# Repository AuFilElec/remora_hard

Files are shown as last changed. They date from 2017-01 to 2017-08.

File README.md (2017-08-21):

# remora_hard
PCB Remora v1.4 - gestionnaire de chauffage électrique

La **Remora** permet de piloter 7 zones de chauffage électrique via les fils pilotes. Mais aussi de récupérer la téléinformation de votre compteur Enedis et piloter votre ballon d'eau chaude.

**Schematic**

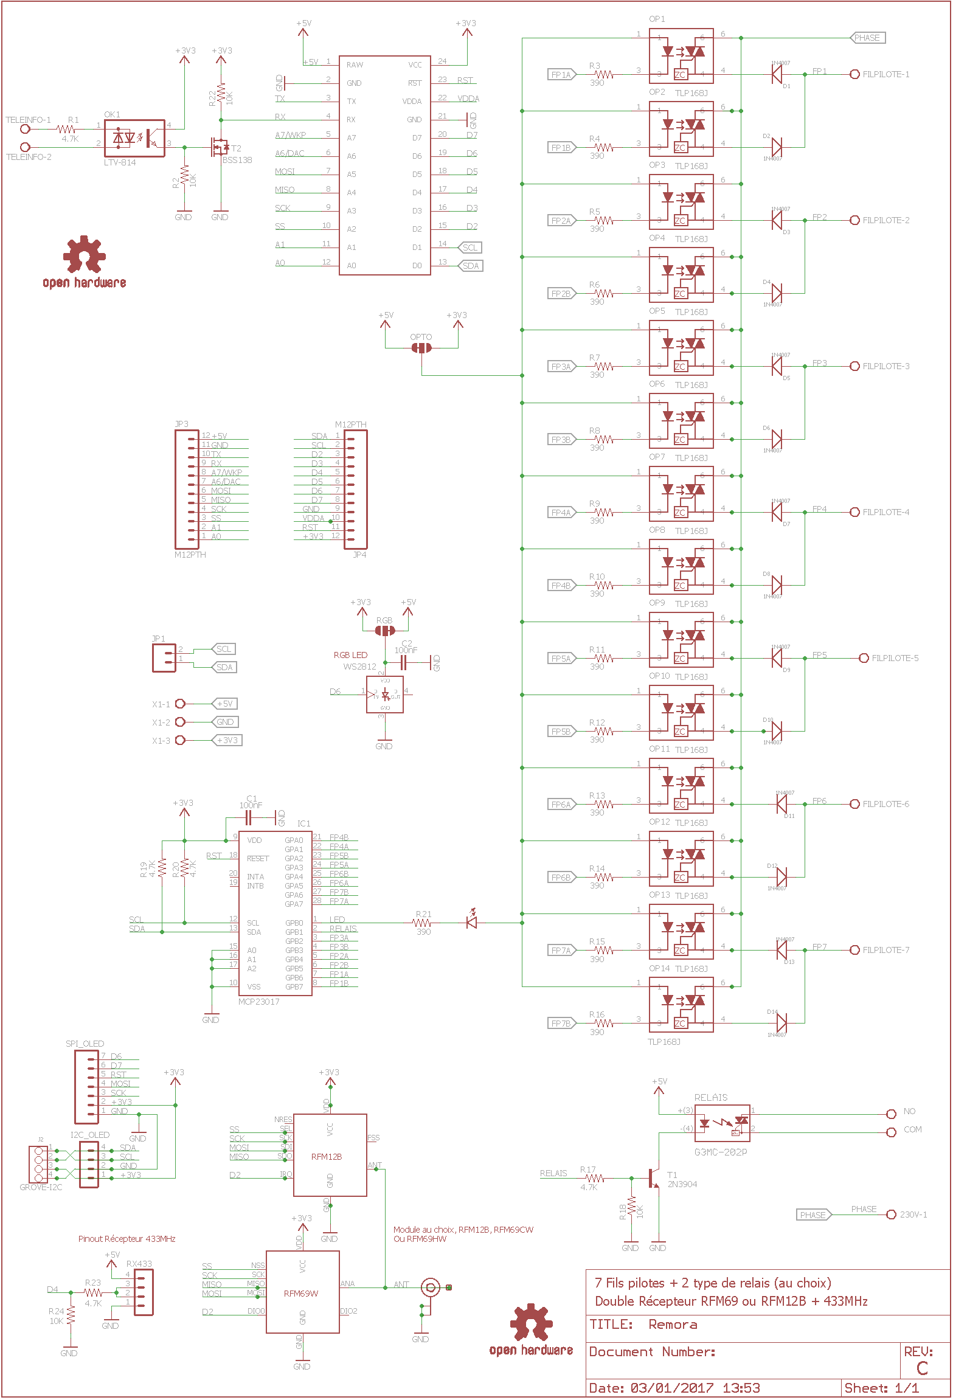
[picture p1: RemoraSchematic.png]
schéma carte Remora


**PCB**

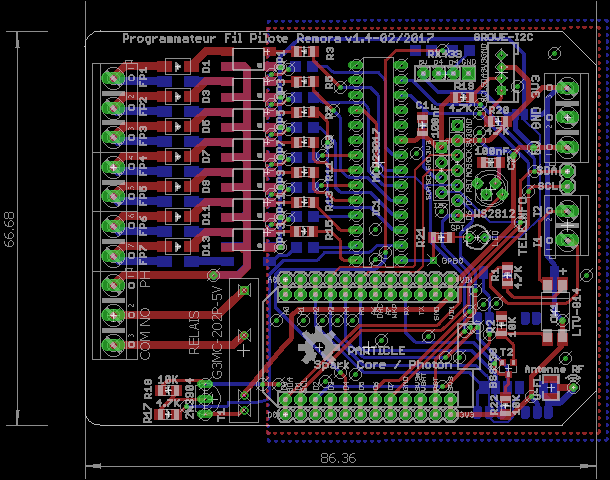
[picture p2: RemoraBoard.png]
PCB Remora v1.4


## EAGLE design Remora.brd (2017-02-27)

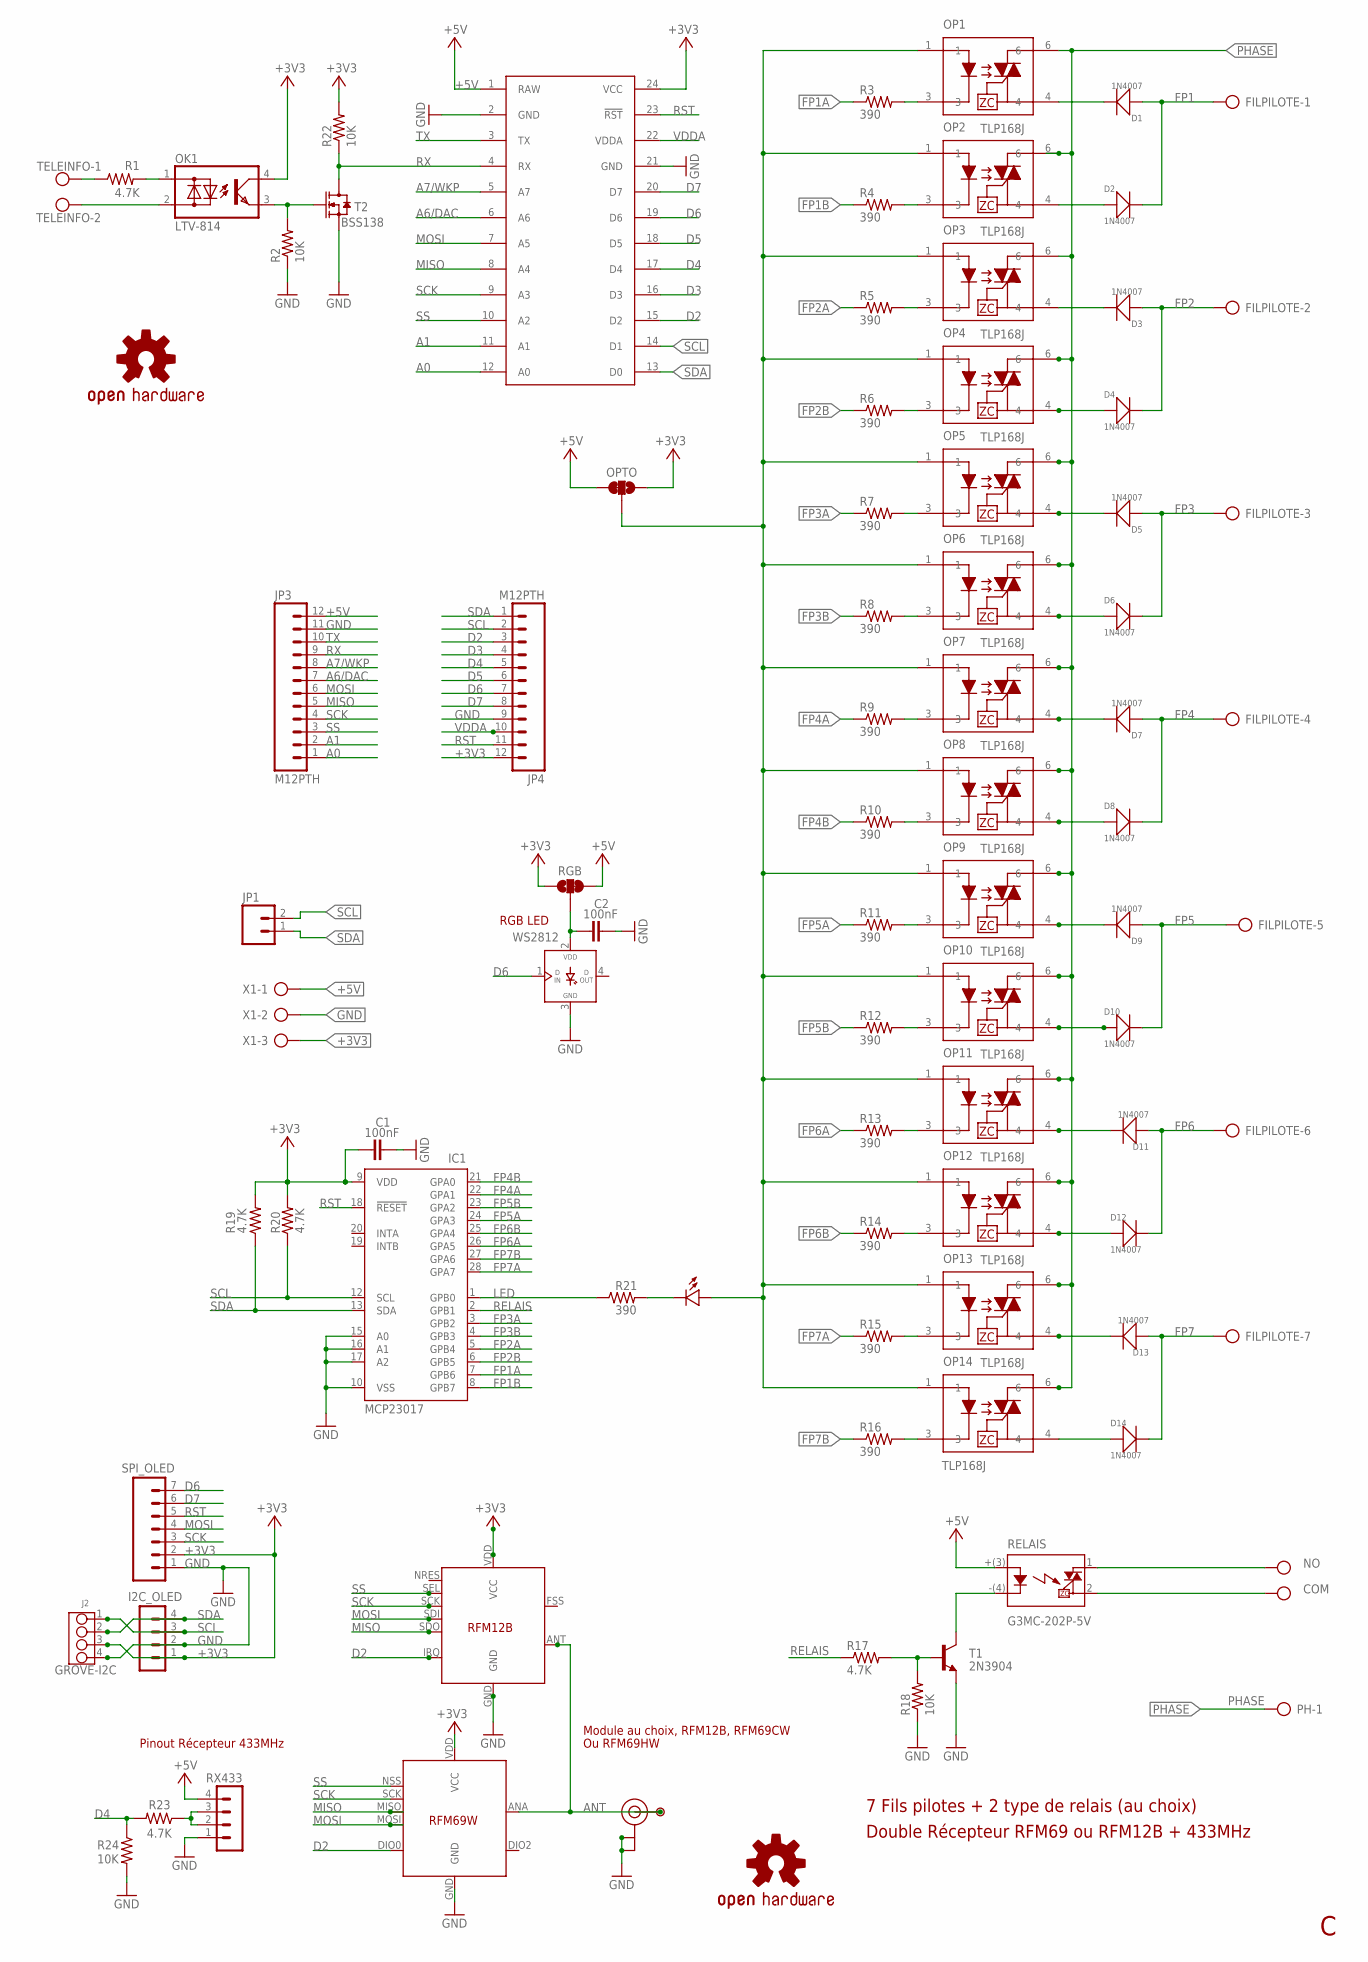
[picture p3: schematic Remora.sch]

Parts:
C1, C2: 100nF; 1206-CAP
D1, D2, D3, D4, D5, D6, D7, D8, D9, D10, D11, D12, D13, D14: 1N4007; DO-214AC
FILPILOTE: AK500/7
I2C_OLED: CON_HEADER_1X04'SMALL''; M1X4
IC1: MCP23017; DIL28-3
J2: GROVE-I2C; 4P-2.0
JP1: M02PTH; 1X02
JP3, JP4: M12PTH; 1X12-SMALL-PADS
LED: LED3MM
LOGO1, LOGO2: OSHW-LOGOL; OSHW-LOGO-L
OK1: LTV-814; DIL4-SMD
OP1, OP2, OP3, OP4, OP5, OP6, OP7, OP8, OP9, OP10, OP11, OP12, OP13, OP14: TLP168J; MFSOP-4-HANDSOLDER
OPTO: JUMPER-PAD-3-2OF3_NC_BY_TRACE_LARGE; PAD-JUMPER-3-2OF3_NC_BY_TRACE_YES_SILK_LARGE
P1: PADSMALL; PAD-SMALL
PARTICLE: Spark/Photon; SPARK_CORE
PH: AK500/3
R1, R17, R19, R20, R23: 4.7K; 1206-RES
R2, R18, R22, R24: 10K; 1206-RES
R3, R4, R5, R6, R7, R8, R9, R10, R11, R12, R13, R14, R15, R16, R21: 390; 1206-RES
RELAIS: G3MC-202P-5V; SIP-4
RGB: JUMPER-PAD-3-2OF3_NC_BY_TRACE_SMALL; PAD-JUMPER-3-2OF3_NC_BY_TRACE_YES_SILK_FULL_BOX
RX433: CON_HEADER_1X04'NO_LOCK'; 1X04_NO_LOCK
SPI_OLED: CON_HEADER_1X07'SMALL'; M1X7
T1: 2N3904; TO92-EBC
T2: BSS138; SOT23
TELEINFO: AK500/2
U$2: RFM12B; RFM12B-MINPADS
U$3: RFM69W; RFM69W-MINPADS
U-FL: U.FL
WS2812: RGB LED; WS2812-PTH
X1: AK500/3

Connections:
+3V3: C1.1, I2C_OLED.1, IC1.9 (VDD), J2.3, JP4.12, OK1.4 (C), OPTO.1, PARTICLE.24 (VCC), R19.2, R20.2, R22.2, RGB.1, SPI_OLED.2, U$2.VDD (VCC), U$3.VDD (VCC), X1.3
+5V: JP3.12, OPTO.3, PARTICLE.1 (RAW), RELAIS.+(3) (3), RGB.3, RX433.4, X1.1
A0: JP3.1, PARTICLE.12 (A0)
A1: JP3.2, PARTICLE.11 (A1)
A6/DAC: JP3.7, PARTICLE.6 (A6)
A7/WKP: JP3.8, PARTICLE.5 (A7)
ANT: P1.1, U$2.ANT, U$3.ANA (ANT), U-FL.3 (SIGNAL)
COM: PH.3, RELAIS.2
D2: JP4.3, PARTICLE.15 (D2), U$2.IRQ, U$3.DIO0
D3: JP4.4, PARTICLE.16 (D3)
D4: JP4.5, PARTICLE.17 (D4), R23.2, R24.1
D5: JP4.6, PARTICLE.18 (D5)
D6: JP4.7, PARTICLE.19 (D6), SPI_OLED.7, WS2812.1 (DIN)
D7: JP4.8, PARTICLE.20 (D7), SPI_OLED.6
FP1: D1.1 (+), D2.2 (-), FILPILOTE.1
FP1A: IC1.7 (GPB6), R3.1
FP1B: IC1.8 (GPB7), R4.1
FP2: D3.1 (+), D4.2 (-), FILPILOTE.2
FP2A: IC1.5 (GPB4), R5.1
FP2B: IC1.6 (GPB5), R6.1
FP3: D5.1 (+), D6.2 (-), FILPILOTE.3
FP3A: IC1.3 (GPB2), R7.1
FP3B: IC1.4 (GPB3), R8.1
FP4: D7.1 (+), D8.2 (-), FILPILOTE.4
FP4A: IC1.22 (GPA1), R9.1
FP4B: IC1.21 (GPA0), R10.1
FP5: D9.1 (+), D10.2 (-), FILPILOTE.5
FP5A: IC1.24 (GPA3), R11.1
FP5B: IC1.23 (GPA2), R12.1
FP6: D11.1 (+), D12.2 (-), FILPILOTE.6
FP6A: IC1.26 (GPA5), R13.1
FP6B: IC1.25 (GPA4), R14.1
FP7: D13.1 (+), D14.2 (-), FILPILOTE.7
FP7A: IC1.28 (GPA7), R15.1
FP7B: IC1.27 (GPA6), R16.1
GND: C1.2, C2.2, I2C_OLED.2, IC1.10 (VSS), IC1.15 (A0), IC1.16 (A1), IC1.17 (A2), J2.4, JP3.11, JP4.9, PARTICLE.2 (GND), PARTICLE.21 (GND), R2.1, R18.1, R24.2, RX433.1, SPI_OLED.1, T1.E, T2.2 (S), U$2.GND, U$3.GND, U-FL.1 (GND), U-FL.2 (GND), WS2812.3 (GND), X1.2
LED: IC1.1 (GPB0), R21.1
MISO: JP3.5, PARTICLE.8 (A4), U$2.SDO, U$3.MISO
MOSI: JP3.6, PARTICLE.7 (A5), SPI_OLED.4, U$2.SDI, U$3.MOSI
unnamed: D1.2 (-), OP1.4
unnamed: D2.1 (+), OP2.4
unnamed: OK1.2 (AC2), TELEINFO.2
unnamed: OK1.1 (AC1), R1.2
unnamed: R1.1, TELEINFO.1
unnamed: LED.MINUS, R21.2
unnamed: OP1.3, R3.2
unnamed: OP2.3, R4.2
unnamed: OP3.3, R5.2
unnamed: OP4.3, R6.2
unnamed: OP5.3, R7.2
unnamed: OP6.3, R8.2
unnamed: OP7.3, R9.2
unnamed: OP8.3, R10.2
unnamed: RELAIS.-(4) (4), T1.C
unnamed: C2.1, RGB.2, WS2812.2 (VDD)
unnamed: OK1.3 (E), R2.2, T2.1 (G)
unnamed: OP9.3, R11.2
unnamed: LED.PLUS, OP1.1, OP2.1, OP3.1, OP4.1, OP5.1, OP6.1, OP7.1, OP8.1, OP9.1, OP10.1, OP11.1, OP12.1, OP13.1, OP14.1, OPTO.2
unnamed: R17.2, R18.2, T1.B
unnamed: D3.2 (-), OP3.4
unnamed: D5.2 (-), OP5.4
unnamed: D4.1 (+), OP4.4
unnamed: D7.2 (-), OP7.4
unnamed: D6.1 (+), OP6.4
unnamed: D8.1 (+), OP8.4
unnamed: OP10.3, R12.2
unnamed: OP14.3, R16.2
unnamed: D9.2 (-), OP9.4
unnamed: OP11.3, R13.2
unnamed: OP12.3, R14.2
unnamed: D10.1 (+), OP10.4
unnamed: D12.1 (+), OP12.4
NO: PH.2, RELAIS.1
PHASE: OP1.6, OP2.6, OP3.6, OP4.6, OP5.6, OP6.6, OP7.6, OP8.6, OP9.6, OP10.6, OP11.6, OP12.6, OP13.6, OP14.6, PH.1
RELAIS: IC1.2 (GPB1), R17.1
RST: IC1.18 (!RESET), JP4.11, PARTICLE.23 (!RST), SPI_OLED.5
RX: JP3.9, PARTICLE.4 (RX), R22.1, T2.3 (D)
RX433: R23.1, RX433.2, RX433.3
S$1: D11.2 (-), OP11.4
S$3: D13.2 (-), OP13.4
S$5: OP13.3, R15.2
S$11: D14.1 (+), OP14.4
SCK: JP3.4, PARTICLE.9 (A3), SPI_OLED.3, U$2.SCK, U$3.SCK
SCL: I2C_OLED.3, IC1.12 (SCL), J2.1, JP1.2, JP4.2, PARTICLE.14 (D1), R20.1
SDA: I2C_OLED.4, IC1.13 (SDA), J2.2, JP1.1, JP4.1, PARTICLE.13 (D0), R19.1
SS: JP3.3, PARTICLE.10 (A2), U$2.SEL, U$3.NSS (SEL)
TX: JP3.10, PARTICLE.3 (TX)
VDDA: JP4.10, PARTICLE.22 (VDDA)

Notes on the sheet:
7 Fils pilotes + 2 type de relais (au choix)
Module au choix, RFM12B, RFM69CW
Ou RFM69HW
Pinout Récepteur 433MHz
Double Récepteur RFM69 ou RFM12B + 433MHz
RGB LED

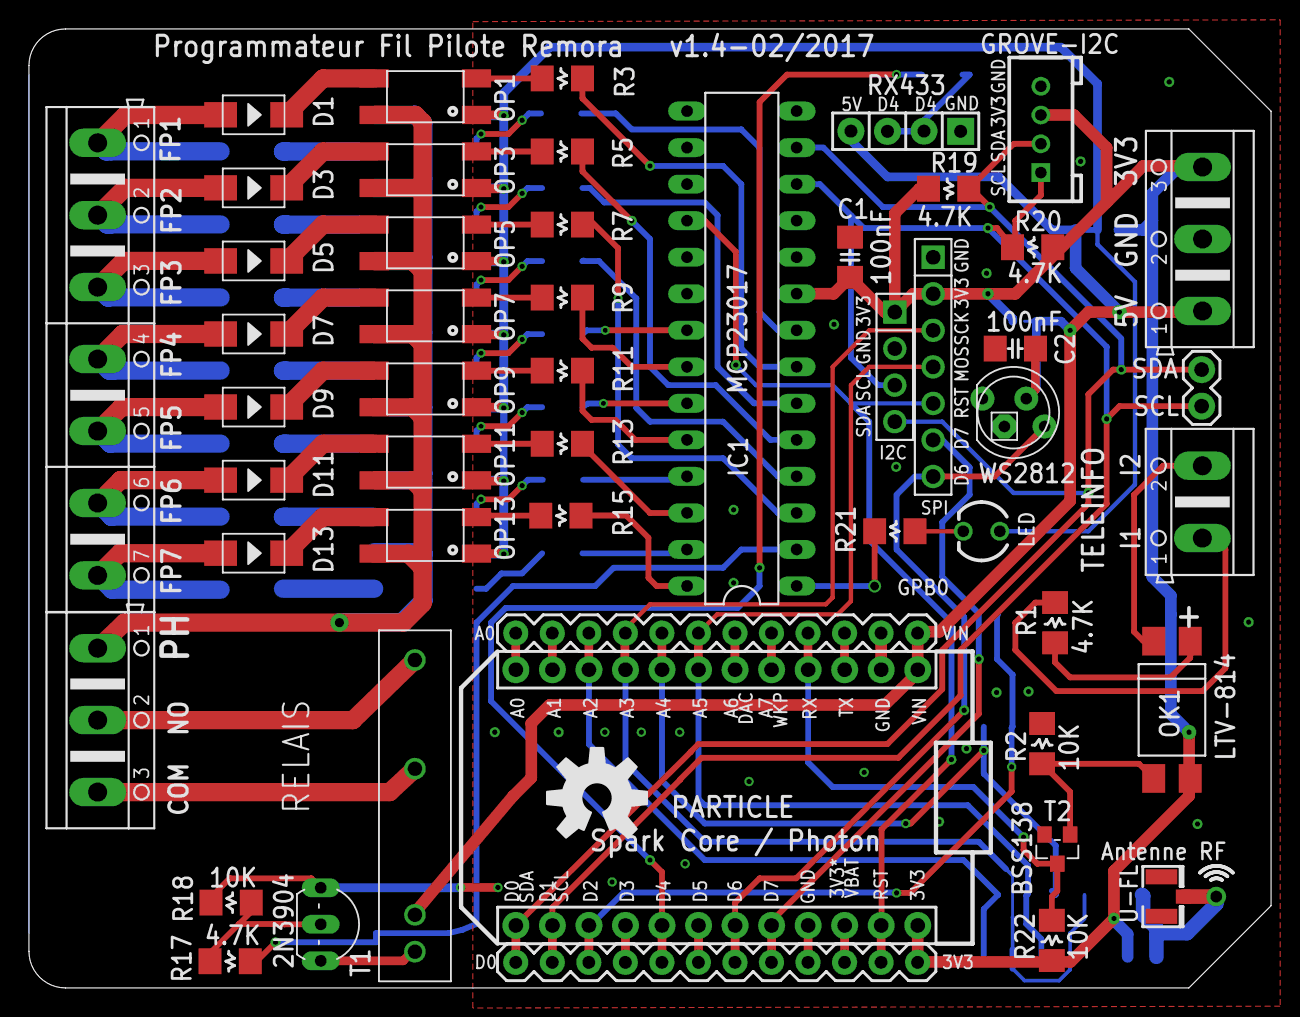
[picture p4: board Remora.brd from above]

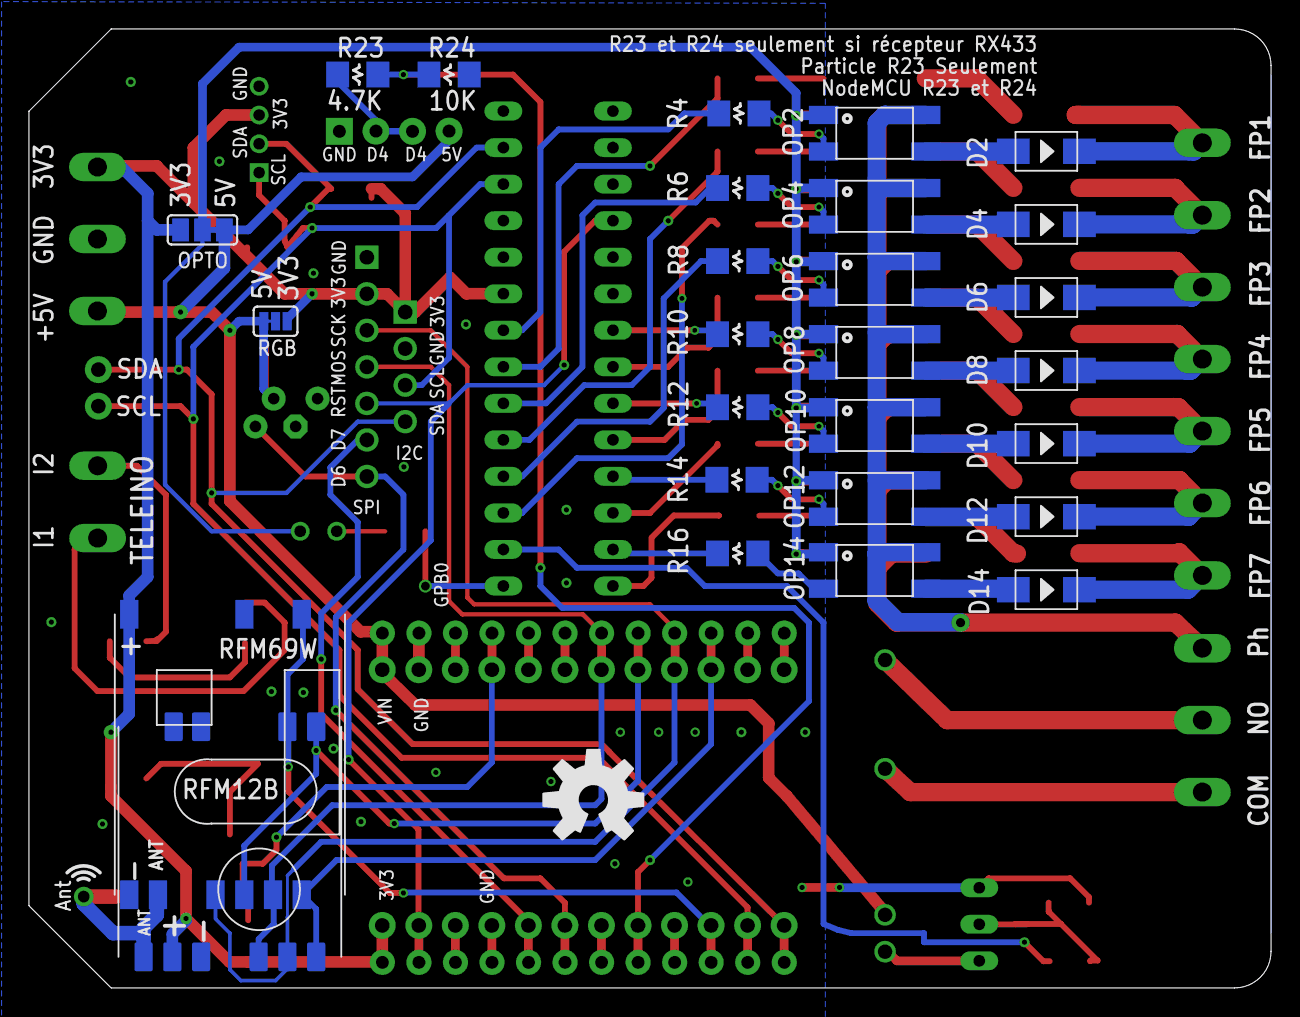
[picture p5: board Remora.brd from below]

Board: 2 copper layers, 86.4 x 66.7 mm, 81 parts (28 on the bottom side), 88 nets.

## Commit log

2017-01-03 Ajout de la nouvelle version de la board Remora v1.4
    [Remora.brd, Remora.sch]
2017-01-03 Mise à jour du PCB et ajout d'images
    [Remora.brd, Remora.sch]
2017-01-03 Ajout des images du schéma et du PCB de la Remora
2017-02-25 Correction d'une anomalie de connexion de la LED rouge
    [Remora.brd]
2017-02-26 Correction d'anomalie sur la route de la LED
    [Remora.brd]
2017-02-26 Mise à jour de l'image du PCB
2017-02-26 Correction d'anomalie de la route de la phase
    [Remora.brd, Remora.sch]
2017-02-26 Suppression d'une valeur inutile
    [Remora.brd]
2017-02-26 Mise à jour des values
    [Remora.brd, Remora.sch]
2017-02-27 Modification pour export gerbers
    [Remora.brd]
2017-02-27 Correction d'une erreur dans la couche dimension
    [Remora.brd]

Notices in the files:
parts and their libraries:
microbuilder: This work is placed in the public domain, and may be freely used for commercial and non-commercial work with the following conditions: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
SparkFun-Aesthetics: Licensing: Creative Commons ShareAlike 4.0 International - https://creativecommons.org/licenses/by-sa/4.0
